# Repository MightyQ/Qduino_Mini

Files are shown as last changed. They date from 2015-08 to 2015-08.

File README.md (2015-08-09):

Qduino Mini

The Qduino Mini is *perfect* to embed in your electronics projects, it's super small, inexpensive, has a battery connector & charger built-in, & a fuel gauge that can tell you when to charge the battery!

The **Qduino Mini is Arduino-compatible & 100% open source, hardware and software** meaning that making and programming your first circuit is a breeze.  Hardware is hard, so we decided to make it a little bit easier.  All of the design files, including EAGLE board files, schematic, and code have been released under an open source license.  Here's what it includes:

* **Battery Charger Circuit** - just plug in USB and it charges the battery with the auto switching circuit - there's no extra charger needed & no digging the battery out of your project so you can charge & program at the same time over USB!
* **Battery Fuel Gauge** - guessing on when your project runs out of juice?  We've got you covered - we have a simple monitor library for your battery so you can remind yourself when it needs a little extra juice.
* **Ultra small, Ultra thin, Ultra light** - The Qduino Mini itself is 0.8in x 1.5in (2cm x 3.9cm) & 0.18oz (5 grams), perfect for quadcopters, drones or high altitude balloon projects.  Both the Qduino Mini and the batteries (LiPos) used to power the board fit are super compact & thin, just right for embedding in your projects.

######Tech Specs:

* **ATmega32U4 Processor** - Arduino Leonardo Compatible
* 32KB Flash Storage
* 2.5KB SRAM
* 1KB EEPROM
* 3.3V @ 8MHz
* 20 Digital I/O // 14 Dedicated
* 12 Analog Channels // 6 Dedicated
* 7 Digital I/O also PWM channels
* SPI, I2C, UART available
* Two RGB LEDs built-in - one for: Charge Status, TX, RX, and the * other user programmable
* **TPS78233** 3.3V 150mA Regulator
* **MCP73832** LiPo Battery Charger
* **MAX17048** LiPo Battery Fuel Gauge

The Qduino Mini is 100% made in the USA! Every board is made and quality tested at SparkFun Electronics, in Niwot, CO.

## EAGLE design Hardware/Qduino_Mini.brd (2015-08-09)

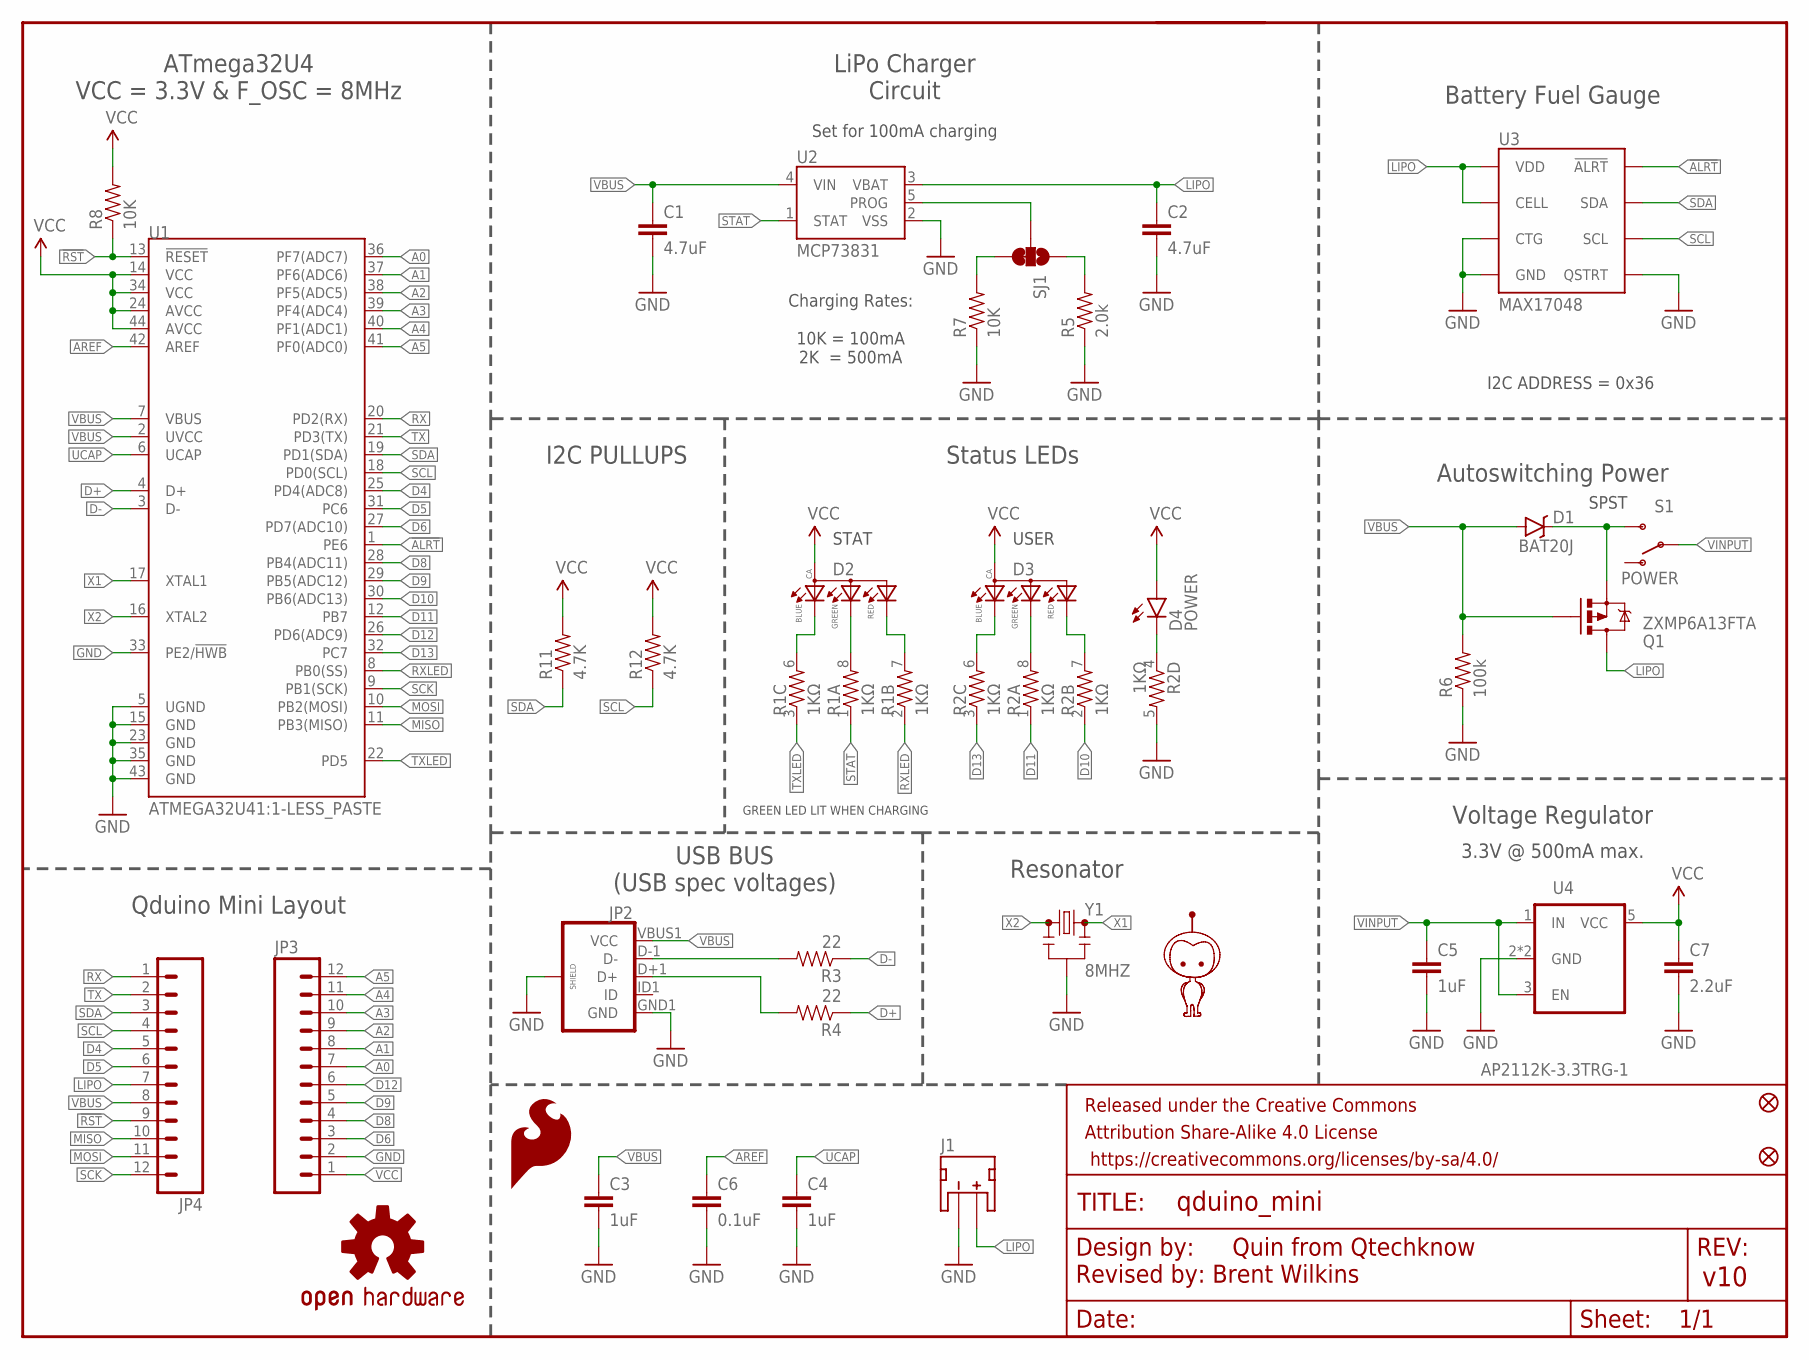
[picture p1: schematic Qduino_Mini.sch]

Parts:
C1, C2: 4.7uF; 0603-CAP
C3, C4, C5: 1uF; 0603-CAP
C6: 0.1uF; 0603-CAP
C7: 2.2uF; 0603-CAP
D1: BAT20J; SOD-323
D2, D3: 0.13_RGB_LEDPLCC; P-LCC-4-3
D4: POWER; LED-0603
FID1, FID2: FIDUCIALUFIDUCIAL; MICRO-FIDUCIAL
FRAME2: FRAME-LETTER; CREATIVE_COMMONS
J1: LiPo; JST-2-SMD
JP2: USB_MICROB_PLUGCONN-11752; USB-B-MICRO-SMD_V03
JP3, JP4: M12PTH; 1X12
LOGO1: OSHW-LOGOS; OSHW-LOGO-S
LOGO2: SFE_LOGO_FLAME.1_INCH; SFE_LOGO_FLAME_.1
Q1: ZXMP6A13FTA; SOT23-3
R1, R2: 1KΩ; 0603-ARV
R3, R4: 22; 0603-RES
R5: 2.0k; 0603-RES
R6: 100k; 0603-RES
R7, R8: 10K; 0603-RES
R11, R12: 4.7K; 0603-RES
S1: POWER; SWITCH-SPST-SMD-A
SJ1: JUMPER-PAD-3-2OF3_NC_BY_TRACE_SMALL; PAD-JUMPER-3-2OF3_NC_BY_TRACE_YES_SILK_FULL_BOX
U1: ATMEGA32U41:1-LESS_PASTE; QFN-44-NOPAD_1:1-LESS_PASTE
U2: MCP73831; SOT23-5
U3: MAX17048; DFN-8
U4: AP2112K-3.3TRG-1; SOT23-5
U5: MIGHTYQ-L-SILK; LOGO-LARGE-SILK
Y1: 8MHZ; RESONATOR-SMD

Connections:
!ALRT: U1.1 (PE6), U3.P$5 (!ALRT)
!RST: JP4.9, R8.1, U1.13 (!RESET)
A0: JP3.7, U1.36 (PF7(ADC7))
A1: JP3.8, U1.37 (PF6(ADC6))
A2: JP3.9, U1.38 (PF5(ADC5))
A3: JP3.10, U1.39 (PF4(ADC4))
A4: JP3.11, U1.40 (PF1(ADC1))
A5: JP3.12, U1.41 (PF0(ADC0))
AREF: C6.1, U1.42 (AREF)
D4: JP4.5, U1.25 (PD4(ADC8))
D5: JP4.6, U1.31 (PC6)
D6: JP3.3, U1.27 (PD7(ADC10))
D8: JP3.4, U1.28 (PB4(ADC11))
D9: JP3.5, U1.29 (PB5(ADC12))
D10: R2.2 (1), U1.30 (PB6(ADC13))
D11: R2.1, U1.12 (PB7)
D12: JP3.6, U1.26 (PD6(ADC9))
D13: R2.3 (1), U1.32 (PC7)
D+: R4.1, U1.4 (D+)
D-: R3.1, U1.3 (D-)
GND: C1.2, C2.2, C3.2, C4.2, C5.2, C6.2, C7.2, J1.1 (-), JP2.GND1 (GND), JP2.SHIELD1 (SHIELD), JP2.SHIELD2 (SHIELD), JP2.SHIELD3 (SHIELD), JP3.2, R2.5 (2), R5.1, R6.1, R7.1, U1.5 (UGND), U1.15 (GND), U1.23 (GND), U1.33 (PE2/!HWB), U1.35 (GND), U1.43 (GND), U2.2 (VSS), U3.P$1 (CTG), U3.P$4 (GND), U3.P$6 (QSTRT), U3.P$9 (GND), U4.2 (GND), U4.4 (GND), Y1.2
INMOSFET: D1.C, Q1.2 (S), S1.3 (S)
LIPO: C2.1, J1.2 (+), JP4.7, Q1.3 (D), U2.3 (VBAT), U3.P$2 (CELL), U3.P$3 (VDD)
MISO: JP4.10, U1.11 (PB3(MISO))
MOSI: JP4.11, U1.10 (PB2(MOSI))
unnamed: D2.3 (BLUE), R1.6 (2)
unnamed: D2.2 (GREEN), R1.8 (2)
unnamed: D3.3 (BLUE), R2.6 (2)
unnamed: D4.C, R2.4 (1)
unnamed: R7.2, SJ1.3
unnamed: R5.2, SJ1.1
unnamed: D3.2 (GREEN), R2.8 (2)
unnamed: D2.1 (RED), R1.7 (2)
unnamed: D3.1 (RED), R2.7 (2)
PROG: SJ1.2, U2.5 (PROG)
RX: JP4.1, U1.20 (PD2(RX))
RXLED: R1.2 (1), U1.8 (PB0(SS))
SCK: JP4.12, U1.9 (PB1(SCK))
SCL: JP4.4, R12.1, U1.18 (PD0(SCL)), U3.P$7 (SCL)
SDA: JP4.3, R11.1, U1.19 (PD1(SDA)), U3.P$8 (SDA)
STAT: R1.1, U2.1 (STAT)
TX: JP4.2, U1.21 (PD3(TX))
TXLED: R1.3 (1), U1.22 (PD5)
UCAP: C4.1, U1.6 (UCAP)
UD+: JP2.D+1 (D+), R4.2
UD-: JP2.D-1 (D-), R3.2
VBUS: C1.1, C3.1, D1.A, JP2.VBUS1 (VCC), JP4.8, Q1.1 (G), R6.2, U1.2 (UVCC), U1.7 (VBUS), U2.4 (VIN)
VCC: C7.1, D2.4 (ANODE), D3.4 (ANODE), D4.A, JP3.1, R8.2, R11.2, R12.2, U1.14 (VCC), U1.24 (AVCC), U1.34 (VCC), U1.44 (AVCC), U4.5 (VCC)
VINPUT: C5.1, S1.2, U4.1 (IN), U4.3 (EN)
X1: U1.17 (XTAL1), Y1.3
X2: U1.16 (XTAL2), Y1.1

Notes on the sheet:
Set for 100mA charging
USB BUS (USB spec voltages)
Resonator
Status LEDs
3.3V @ 500mA max.
SPST
ATmega32U4 VCC = 3.3V & F_OSC = 8MHz
Qduino Mini Layout
LiPo Charger Circuit
Battery Fuel Gauge
Voltage Regulator
Autoswitching Power
Charging Rates: 10K = 100mA 2K = 500mA
I2C PULLUPS
Revised by: Brent Wilkins
I2C ADDRESS = 0x36
USER
STAT
GREEN LED LIT WHEN CHARGING

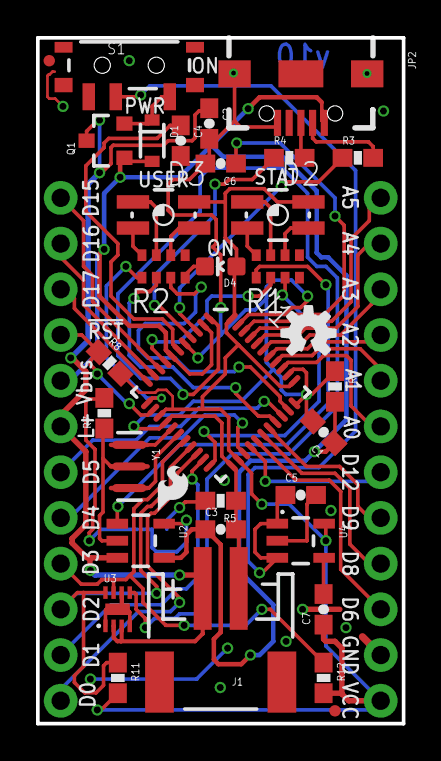
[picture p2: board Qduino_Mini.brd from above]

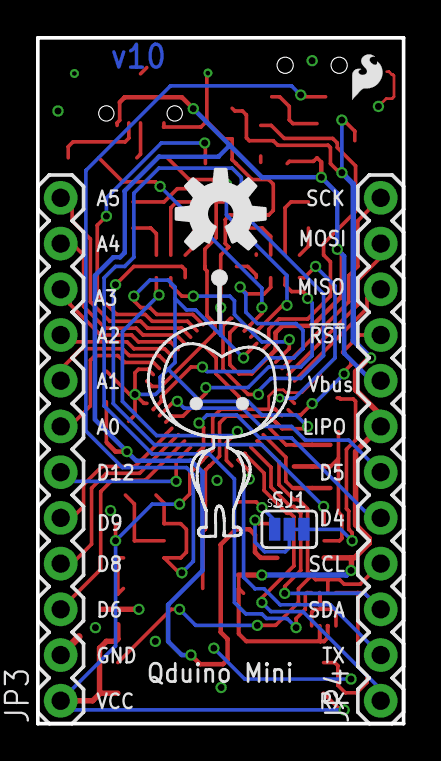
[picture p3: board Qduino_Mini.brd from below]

Board: 2 copper layers, 20.3 x 38.1 mm, 41 parts (6 on the bottom side), 51 nets.

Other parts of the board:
LOGO3: SFE_LOGO_FLAME.1_INCH; SFE_LOGO_FLAME_.1@1
U$4: OSHW-LOGO-M

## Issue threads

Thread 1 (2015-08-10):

Correct Datasheet?

fatdollar, 2015-08-10:
I was looking at the schematic and noticed that the included datasheet for the fuel gauge is for the MAX17043/MAX17044.  In the schematic however, it is using a MAX17048.

The 2 datasheets are similar but not exactly the same.  I could just be a little bit too worried but I thought I'd mention this in case it was a real issue.

Edit:  I just saw in the readme it says the MAX17048 is used.  I replaced the datasheet in my fork and could do a pull request but it's not much to warrant a pull request I think.

MightyQ, 2015-08-11:
Great catch, I will correct this right now

fatdollar, 2015-08-11:
Sounds great!!

Closed 2015-08-11.

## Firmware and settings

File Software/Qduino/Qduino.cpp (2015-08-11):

/**************************************************************************
 *                                                                         *
 * Qduino Mini library w/MAX1704* Driver & RGB PWM control                 *
 *                                                                         *
 * MAX1704+ Driver Forked From:                                            *
 * Matthew Newberry                                                        *
 * mattnewberry@me.com                                                     *
 *                                                                         *
 ***************************************************************************
 *                                                                         * 
 * This program is free software; you can redistribute it and/or modify    *
 * it under the terms of the GNU License.                                  *
 * This program is distributed in the hope that it will be useful,         *
 * but WITHOUT ANY WARRANTY; without even the implied warranty of          *
 * MERCHANTABILITY or FITNESS FOR A PARTICULAR PURPOSE.  See the           *
 * GNU License V2 for more details.                                        *
 *                                                                         *
 ***************************************************************************/

#include "Arduino.h"
#include "Qduino.h"
#include "Wire.h"

void qduino::setup(){
    
    pinMode(13, OUTPUT);
    digitalWrite(13, HIGH);
    pinMode(11, OUTPUT);
    digitalWrite(11, HIGH);
    pinMode(10, OUTPUT);
    digitalWrite(10, HIGH);
}

void qduino::setRGB(int r, int g, int b){
    
    // ratio for R:G:B is 4:7:7 for forward voltage
    
    r = 255 - r; // set all values to opposite values
    g = 255 - g; // because LED is common anode
    b = 255 - b;
    
    int newr = map(r, 0, 255, 0, 146);
    
    analogWrite(10, newr);
    analogWrite(11, g);
    analogWrite(13, b);
}

void qduino::setRGB(Color color){

        switch (color) {
        case RED:
            analogWrite(10, 0);
            analogWrite(11, 255);
            analogWrite(13, 255);
            break;
        case GREEN:
            analogWrite(10, 255);
            analogWrite(11, 0);
            analogWrite(13, 255);
            break;
        case BLUE:
            analogWrite(10, 255);
            analogWrite(11, 255);
            analogWrite(13, 0);
            break;
        case CYAN:
            analogWrite(10, 255);
            analogWrite(11, 0);
            analogWrite(13, 0);
            break;
        case PINK:
            analogWrite(10, 109);
            analogWrite(11, 255);
            analogWrite(13, 0);
            break;
        case WHITE:
            analogWrite(10, 109);
            analogWrite(11, 0);
            analogWrite(13, 0);
            break;
        case PURPLE:
            analogWrite(10, 210);
            analogWrite(11, 255);
            analogWrite(13, 0);
            break;
        case YELLOW:
            analogWrite(10, 100);
            analogWrite(11, 0);
            analogWrite(13, 255);
            break;
        case ORANGE:
            analogWrite(10, 109);
            analogWrite(11, 150);
            analogWrite(13, 255);
            break;
    }
}

void qduino::rainbow(int duration){
    
unsigned int rgbColor[3];
 
    int newduration = map(duration, 1, 5, 500, 3000);
    
  // Start off with red.
  rgbColor[0] = 255;
  rgbColor[1] = 0;
  rgbColor[2] = 0;  
 
  // Choose the colours to increment and decrement.
  for (int decColor = 0; decColor < 3; decColor += 1) {
    int incColor = decColor == 2 ? 0 : decColor + 1;
 
    // cross-fade the two colours.
    for(int i = 0; i < 255; i += 1) {
      rgbColor[decColor] -= 1;
      rgbColor[incColor] += 1;
      
      analogWrite(10, rgbColor[0]);
      analogWrite(11, rgbColor[1]);
      analogWrite(13, rgbColor[2]);
      delayMicroseconds(newduration);
    }
  }
}

void qduino::ledOff(){
    
    analogWrite(10, 255);
    analogWrite(11, 255);
    analogWrite(13, 255);
    
}

int fuelGauge::chargePercentage(){

  byte msb = 0;
  byte lsb = 0;

  readFrom(MAX1704_SOC,msb,lsb);

  int fraction = lsb / 256;
  int percentage = msb + fraction;

  return percentage;
}

void fuelGauge::setup(){
    reset();
    performCommand(MAX1704_QUICK_START, 0x00); // aka quickStart();
}

void fuelGauge::reset(){

  performCommand(MAX1704_POWER_ON_RESET, 0x00);
}

char fuelGauge::getVersion(){

  int value = 0;
  byte msb = 0;
  byte lsb = 0;
  readFrom(MAX1704_VERSION, msb, lsb);
  
    value  = 0xFF00 & (msb<<8);
    value |=   0xFF & lsb;

  return value;
}

void fuelGauge::setThreshold(uint8_t level){

  Wire.beginTransmission(MAX1704_ADDR);
  Wire.write(MAX1704_CONFIG);
  Wire.write(MAX1704_ALERT_LEVEL);
  Wire.write(32 - level);
  Wire.endTransmission();
}

int fuelGauge::currentThreshold(){

  byte msb = 0;
  byte lsb = 0;

  readFrom(MAX1704_CONFIG,msb,lsb);
  byte threshold = lsb & 0x1f;

  return 32 - threshold;
}

boolean fuelGauge::inAlert(){

  byte msb = 0;
  byte lsb = 0;

  readFrom(MAX1704_CONFIG,msb,lsb);
  byte alert = (lsb >>5) & 0x01;

  return int(alert) == 1;
}

boolean fuelGauge::inSleep(){

  byte msb = 0;
  byte lsb = 0;

  readFrom(MAX1704_CONFIG,msb,lsb);
  byte sleep = (lsb >>7) & 0x01; 

  return int(sleep) == 1;
}

void fuelGauge::goToSleep(){
  byte msb = 0;
  byte lsb = 0;

  // Get the current config so we don't wipe any previous settings
  readFrom(MAX1704_CONFIG,msb,lsb);

  // Set SLEEP config bit to 1 to enable
  lsb |= (1<<7);

  // Update config
  Wire.beginTransmission(MAX1704_ADDR);
  Wire.write(MAX1704_CONFIG);
  Wire.write(msb);
  Wire.write(lsb);
  Wire.endTransmission();

  // This delay is here to ensure it's fully asleep before moving on
  delay(150);
}

void fuelGauge::wakeUp(){
  byte msb = 0;
  byte lsb = 0;

  // Get the current config so we don't wipe any previous settings
  readFrom(MAX1704_CONFIG,msb,lsb);
  // Set SLEEP config bit to 0 to disable
  lsb &= ~(1<<7);

  // Update config
  Wire.beginTransmission(MAX1704_ADDR);
  Wire.write(MAX1704_CONFIG);
  Wire.write(msb);
  Wire.write(lsb);
  Wire.endTransmission();

  // This delay is here to ensure it's fully awake before moving on
  delay(150); 
}

void fuelGauge::performCommand(byte address, int value){

  Wire.beginTransmission(MAX1704_ADDR);
  Wire.write(MAX1704_COMMAND);
  Wire.write(address);
  Wire.write(value);
  Wire.endTransmission();
}

void fuelGauge::readFrom(byte address, byte &msb, byte &lsb){

  Wire.beginTransmission(MAX1704_ADDR);
  Wire.write(address);
  Wire.endTransmission();

  Wire.requestFrom(MAX1704_ADDR, 2);

  int numread = Wire.available();
  //if (numread == 2) {
  msb = Wire.read();
  lsb = Wire.read();
  //}
  Wire.endTransmission();
}

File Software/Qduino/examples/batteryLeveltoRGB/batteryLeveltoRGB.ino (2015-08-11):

/* Qduino Fuel Gauge / RGB LED

   This sketch demonstrates both the RGB LED and the
   battery fuel gauge -> the RGB LED is green when 75%
   or more full, yellow 50% - 74%, orange 25% - 49%, red
   when battery is less than 25% full.

   Fuel Gauge Drivers forked from Matt Newberry
   
   created on 25 May 15
   made by Quin Etnyre
*/

#include "Arduino.h"
#include "Wire.h"
#include "Qduino.h"

fuelGauge battery;  // initialize the library

qduino q;

void setup(){
  
 Wire.begin(); 
 battery.setup();
 
 q.setup();
 
}

void loop(){
  int charge = battery.chargePercentage();
  battery.reset();
  
  if(charge >= 75) {
    
    q.setRGB(qduino::GREEN);
    
  } else if(charge >= 50 && charge << 75) {
    
    q.setRGB(qduino::YELLOW);
    
  } else if(charge >= 25 && charge << 50) {
    
    q.setRGB(qduino::ORANGE);
    
  } else if(charge << 25) {
    
    q.setRGB(qduino::RED);
  }
  
  delay(1000);
  
  q.ledOff();
}

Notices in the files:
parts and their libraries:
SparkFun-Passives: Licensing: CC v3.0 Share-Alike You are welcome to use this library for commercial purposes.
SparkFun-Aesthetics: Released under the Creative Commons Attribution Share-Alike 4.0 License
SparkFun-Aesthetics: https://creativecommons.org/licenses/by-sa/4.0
